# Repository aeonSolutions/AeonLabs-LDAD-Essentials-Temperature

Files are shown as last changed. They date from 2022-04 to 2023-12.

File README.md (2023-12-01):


  
 
 

<a href="https://trackgit.com">
trackgit-views
</a>




[](https://www.buymeacoffee.com/migueltomas)

<p align="center">
   
</p>

[Main Catalogue](https://github.com/aeonSolutions/PCB-Prototyping-Catalogue) >> 
[Construction Industry](https://github.com/aeonSolutions/PCB-Prototyping-Catalogue/tree/main/Construction%20Industry)  >>  Smart Technologies for Building Smart Network Connectivity

<p align="right">
 <a href="https://github-com.translate.goog/aeonSolutions/PCB-Prototyping-Catalogue/tree/main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">Change Language</a> <br>
Last update: 01-12-2023
</p>

# AeonLabs LDAD Essentials Temperature
This repo contains the KiCad files for the LDAD Essentials features up to 6 Temperature Sensors has WIFI and BLE connectivity and is powered by a 4.2v Lipo Battery.
This PCB was made to Fit a [Legrand Aftakdoos Leeq](https://www.google.com/search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) 89x43mm waterproof enclosure.

*Don't forget to LIKE , SHARE and subscribe the free whatsApp group* and if you liked this PCB consider buying me a cup of coffee. Links below.




### Status
  revision 1.0 tested and working

If you already tested this PCB send me a message. Thank you

## Revisions
- revision 1.0
  
## Download options
Download this repository if you need the KiCad Files or, download the Gerber files in the release section of this repository

## Liked it ? Get a Free PCB for yourself
Send me your Device or hardware and i will design a custom PCB for it. Free of charge. Contact-me on WhatsApp or email for more info. 

## Q&A WhatsApp Group
If you have any Questions or simply  like this kind of projects and want to stay updated with the latest research ideas and prototypes during the day and week, join the WhatsApp Group
[A.I. Things](https://chat.whatsapp.com/FkNC7u83kuy2QRA5sqjBVg)

## Fully assembled PCB
Alternatively, and if you do not want to build a PCB by yourself and like to buy one:

(https://www.tindie.com/stores/aeonlabs/)

The price starts at 30eur plus postage fees.
(I will also deliver the assembled PCB with all the components in place at a fair aditonal cost).

#### Be supportive of my dedication and work towards technology education and buy me a coffee. Link below.

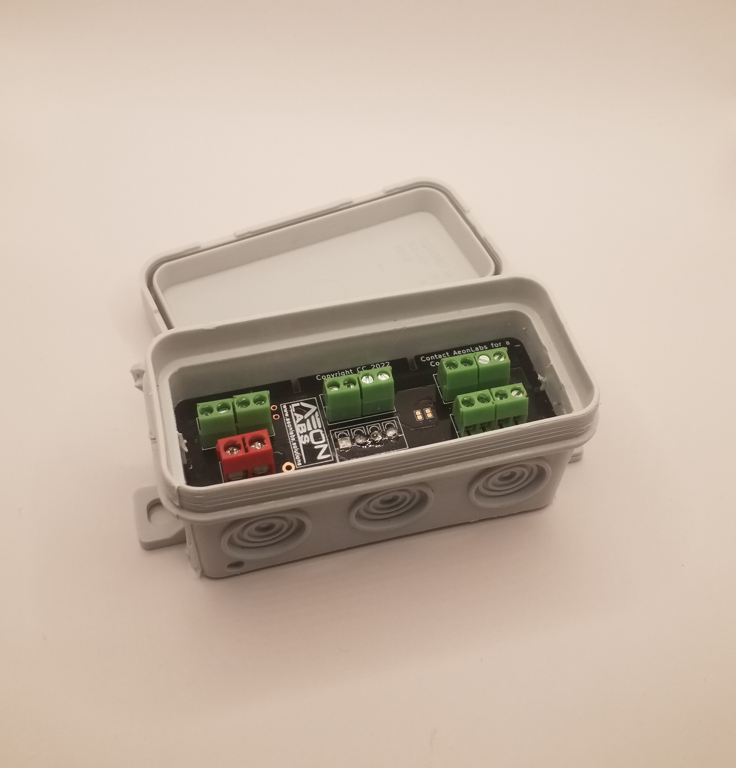
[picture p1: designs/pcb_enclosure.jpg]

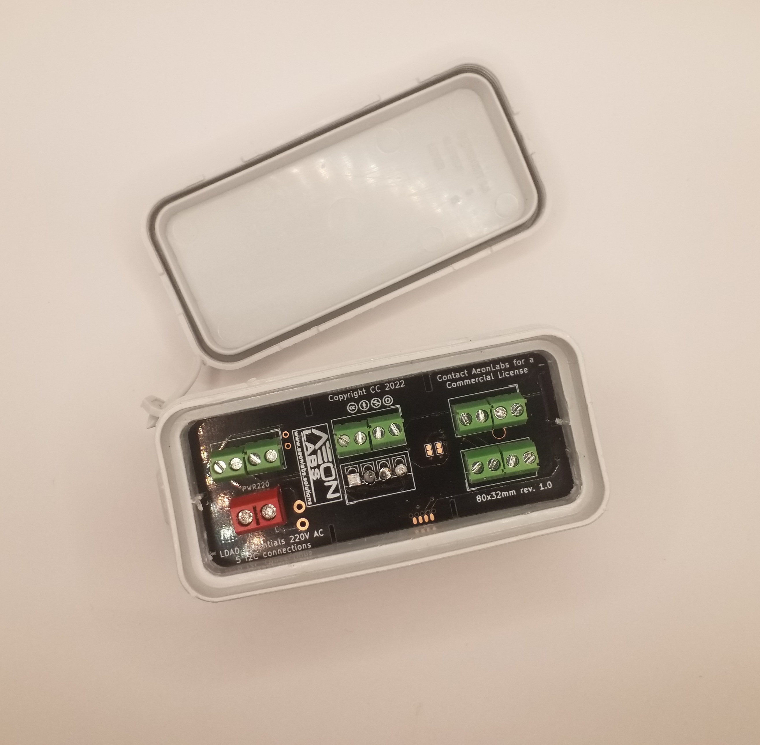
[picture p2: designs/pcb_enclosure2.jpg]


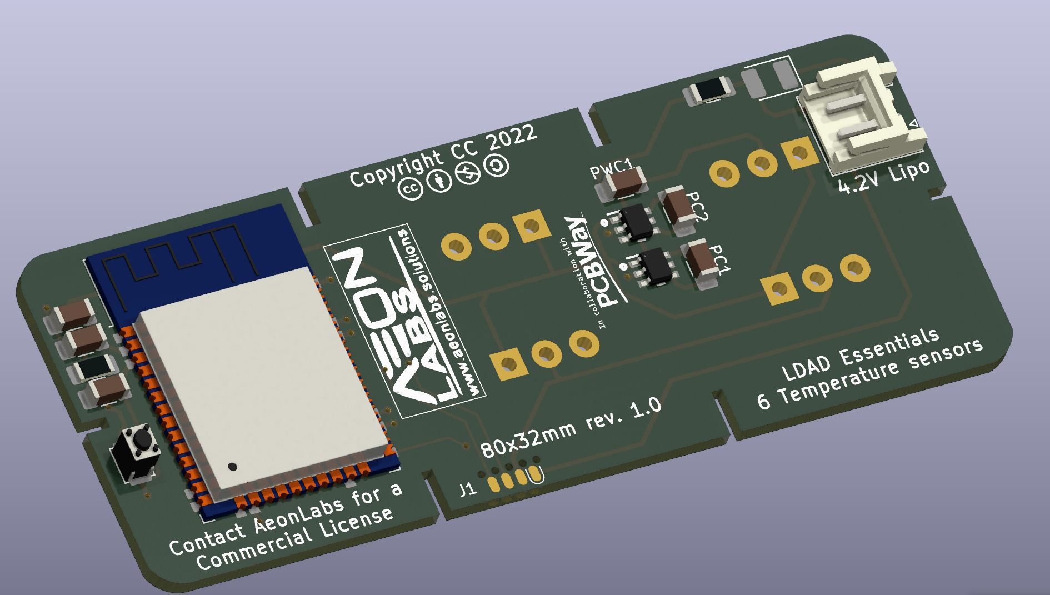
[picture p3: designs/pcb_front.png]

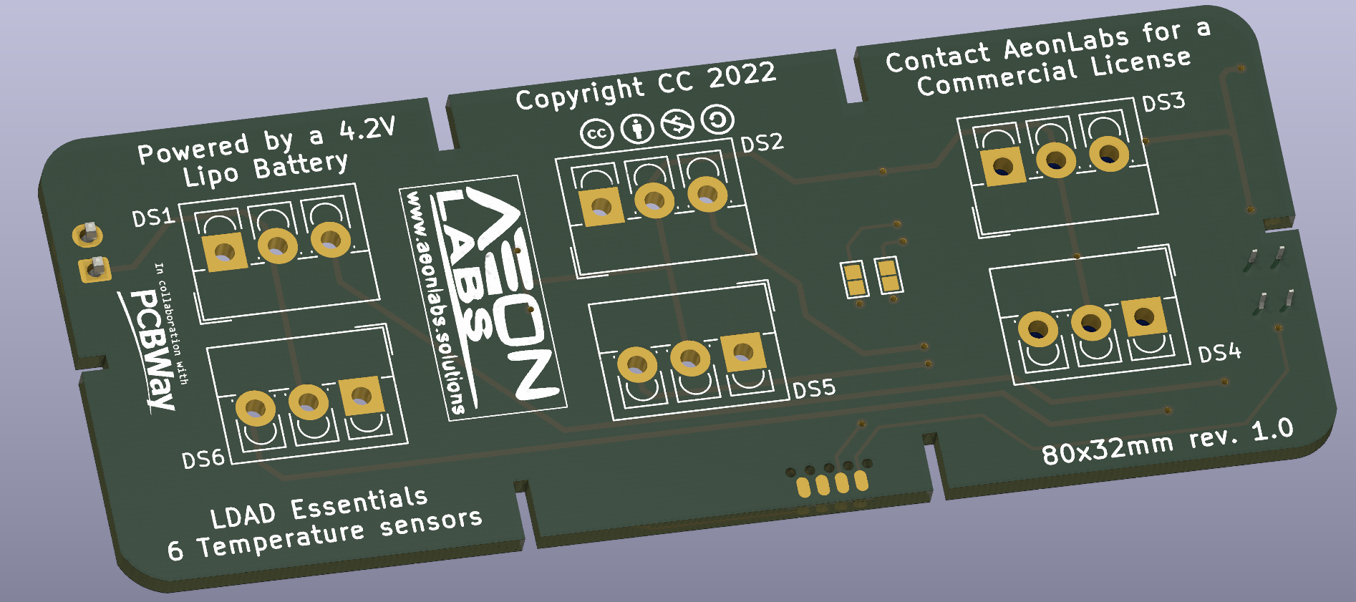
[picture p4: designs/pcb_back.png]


## PCB Parts list
- DC2DC converter HX4002B x2 : https://s.click.aliexpress.com/e/_Ak7IPx
- Capacitor 100nF SMD 1206 : https://s.click.aliexpress.com/e/_AVdmzr
- Capacitor 2.2uF SMD 1206 : https://s.click.aliexpress.com/e/_AVdmzr
- Resistor SMD 1206 330R x3 : https://s.click.aliexpress.com/e/_A7OXrR
- ESP32 WROOM32 x1 : https://s.click.aliexpress.com/e/_AF7N6l
- KF350 Screw pitch 3.5mm Straight 3 Pin pcb terminal block : https://s.click.aliexpress.com/e/_AChDnp

- This PCB connects with the DS18b20 Temperature sensor : https://s.click.aliexpress.com/e/_AWDAMr 

## PCB Enclosure
The enclosure for this PCB can be bought online by searching for "[Legrand Aftakdoos Leeq](https://www.google.com/search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)".

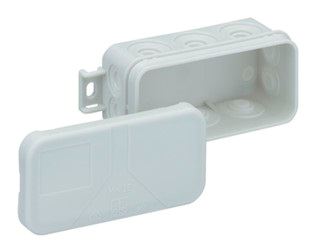
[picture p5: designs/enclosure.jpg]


## Firmware Download 
one can use the PCB in the repository [AeonLabs-MCU-Burner-USB-to-UART-TTL](https://github.com/aeonSolutions/AeonLabs-MCU-Burner-USB-to-UART-TTL) to program the ESP32 WROOM32 MCU on this PCB.

## Author

You can get in touch with me on my LinkedIn Profile:

#### Miguel Tomas



You can also follow my GitHub Profile to stay updated about my latest projects: 

<br>

### Be supportive of my dedication and work towards technology education and buy me a cup of coffee
The PCB Desgin Files i provide here for anyone to use are free. If you like this Smart Device or use it, please consider buying me a cup of coffee, a slice of pizza or a book to help me study, eat and think new PCB design files.

[](https://www.buymeacoffee.com/migueltomas)

<br />

### Make a donation on Paypal
Make a donation on paypal and get a TAX refund*.

(http://paypal.me/mtpsilva)

<br>

### Support all these open hardware projects and become a patreon  
Liked any of my PCB KiCad Designs? Help and Support my open work to all by becomming a LDAD Patreon.
In return I will give a free PCB design in KiCad to all patreon supporters. To learn more go to patreon.com. Link below.

(https://www.patreon.com/ldad)

#

### License

Before proceeding to download any of AeonLabs software solutions for open-source development and/or PCB hardware electronics solutions for open-hardware development make sure you are choosing the right license for your project. See [AeonLabs Solutions for Open Hardware & Source Development](https://github.com/aeonSolutions/PCB-Prototyping-Catalogue/wiki/AeonLabs-Solutions-for-Open-Hardware-&-Source-Development) for more information.

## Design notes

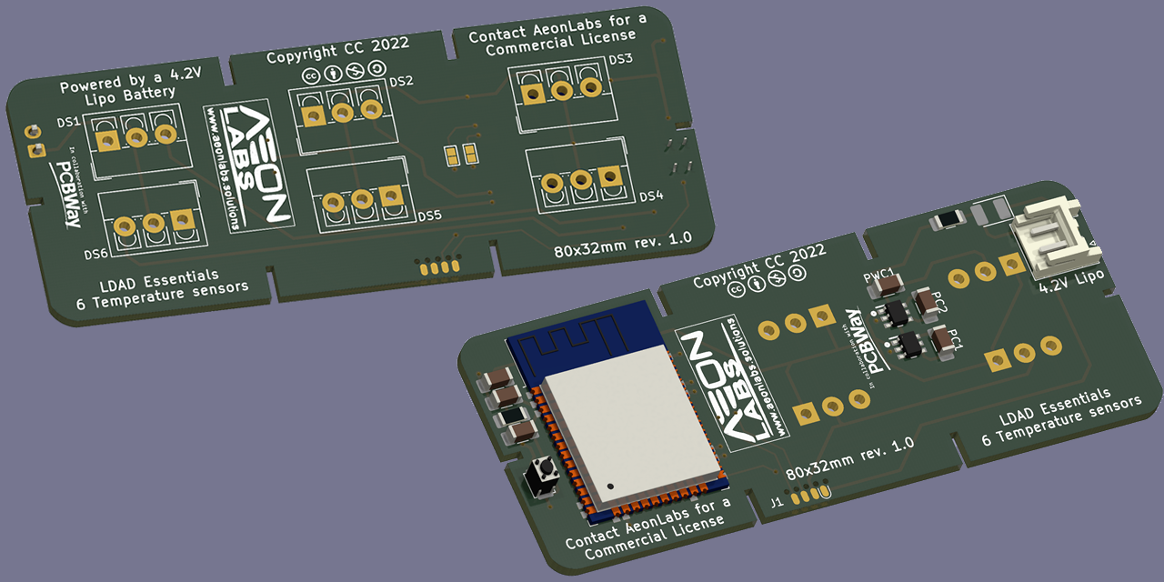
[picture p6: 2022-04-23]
designs/pcb.fw.png

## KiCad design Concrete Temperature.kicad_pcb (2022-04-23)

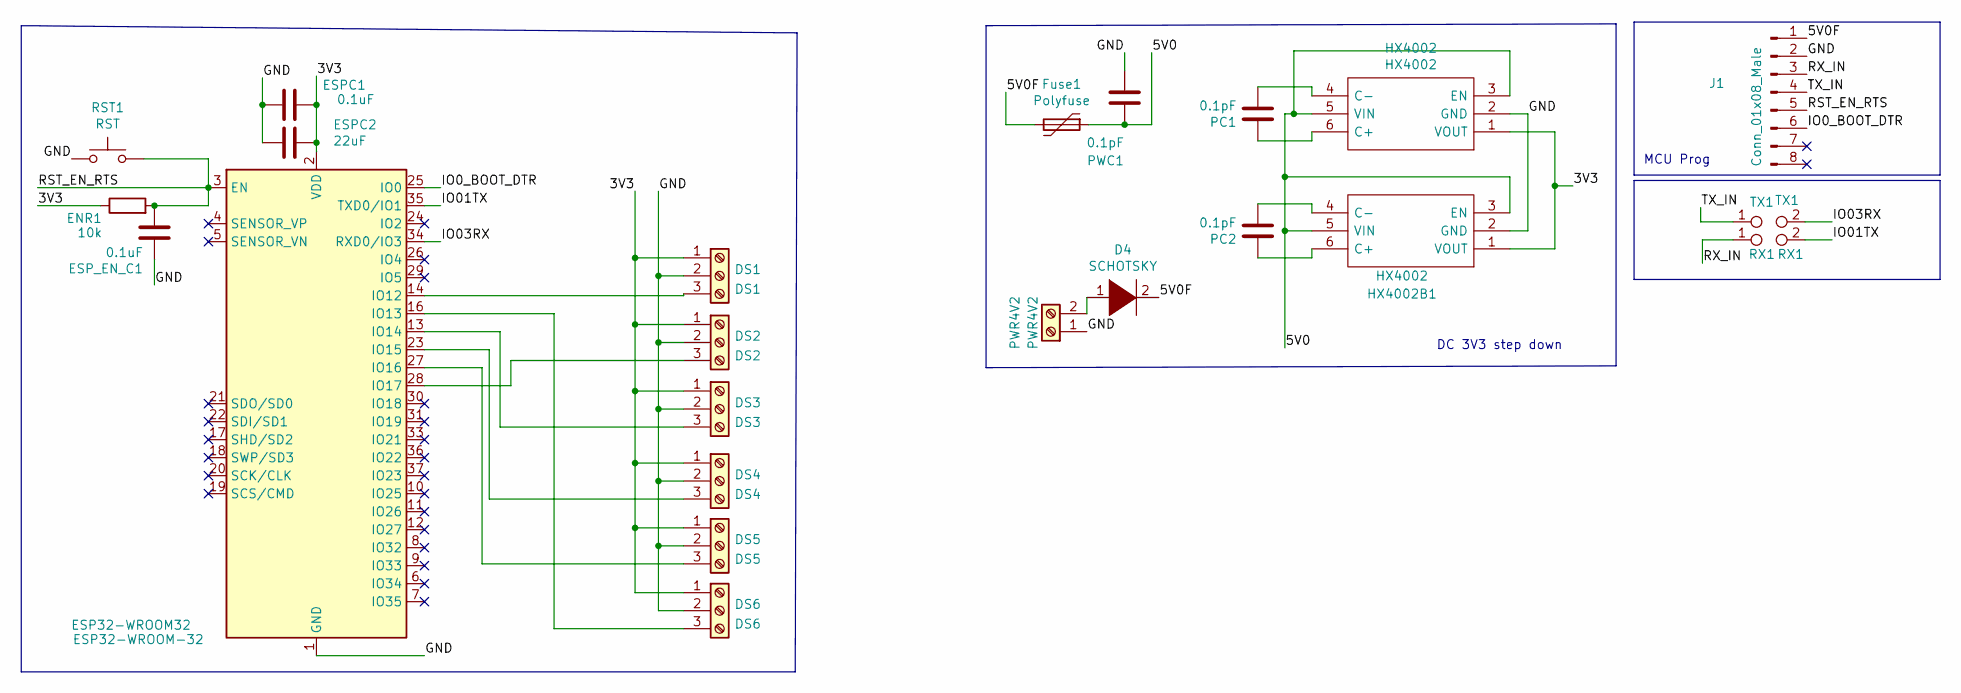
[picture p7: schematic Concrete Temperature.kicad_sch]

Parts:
D4: SCHOTSKY; D_1210_3225Metric_Pad1.42x2.65mm_HandSolder
DS1: DS1; TerminalBlock_4Ucon_1x03_P3.50mm_Vertical
DS2: DS2; TerminalBlock_4Ucon_1x03_P3.50mm_Vertical
DS3: DS3; TerminalBlock_4Ucon_1x03_P3.50mm_Vertical
DS4: DS4; TerminalBlock_4Ucon_1x03_P3.50mm_Vertical
DS5: DS5; TerminalBlock_4Ucon_1x03_P3.50mm_Vertical
DS6: DS6; TerminalBlock_4Ucon_1x03_P3.50mm_Vertical
ENR1: 10k; R_1206_3216Metric_Pad1.30x1.75mm_HandSolder
ESP32-WROOM32: ESP32-WROOM-32
ESPC1: 0.1uF; C_1206_3216Metric_Pad1.33x1.80mm_HandSolder
ESPC2: 22uF; C_1206_3216Metric_Pad1.33x1.80mm_HandSolder
ESP_EN_C1: 0.1uF; C_1206_3216Metric_Pad1.33x1.80mm_HandSolder
Fuse1: Polyfuse; Fuse_1206_3216Metric_Pad1.42x1.75mm_HandSolder
HX4002, HX4002B1: HX4002; HX4002 SOT95 P280X125-6N; Manufacturer_Part_Number HX4002
J1: Conn_01x08_Male; SOIC_clipProgSmall
PC1, PC2: 0.1pF; C_1206_3216Metric_Pad1.33x1.80mm_HandSolder
PWC1: 0.1pF; C_1206_3216Metric_Pad1.33x1.80mm_HandSolder
PWR4V2: PWR4V2; JST_EH_S2B-EH_1x02_P2.50mm_Horizontal
RST1: RST; SW_Push_SPST_NO_Alps_SKRK AliExpress
RX1: RX1; TestPoint_Pad_Bridge_1.0x1.0mm
TX1: TX1; TestPoint_Pad_Bridge_1.0x1.0mm

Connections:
/3V3: DS1.1, DS2.1, DS3.1, DS4.1, DS5.1, DS6.1, ENR1.1, ESP32-WROOM32.2 (VDD), ESPC1.1, ESPC2.1, HX4002.1 (VOUT), HX4002B1.1 (VOUT)
/5V0: Fuse1.1, HX4002.3 (EN), HX4002.5 (VIN), HX4002B1.3 (EN), HX4002B1.5 (VIN), PWC1.1
/5V0F: D4.2 (A), Fuse1.2, J1.1
/GND: DS1.2, DS2.2, DS3.2, DS4.2, DS5.2, DS6.2, ESP32-WROOM32.1 (GND), ESP32-WROOM32.15 (GND), ESP32-WROOM32.38 (GND), ESP32-WROOM32.39 (GND), ESPC1.2, ESPC2.2, ESP_EN_C1.1, HX4002.2 (GND), HX4002B1.2 (GND), J1.2, PWC1.2, PWR4V2.1, RST1.1
/IO0_BOOT_DTR: ESP32-WROOM32.25 (IO0), J1.6
/IO01TX: ESP32-WROOM32.35 (TXD0/IO1), RX1.2
/IO03RX: ESP32-WROOM32.34 (RXD0/IO3), TX1.2
/RST_EN_RTS: ENR1.2, ESP32-WROOM32.3 (EN), ESP_EN_C1.2, J1.5, RST1.2
/RX_IN: J1.3, RX1.1
/TX_IN: J1.4, TX1.1
unnamed: DS1.3, ESP32-WROOM32.14 (IO12)
unnamed: DS2.3, ESP32-WROOM32.28 (IO17)
unnamed: DS3.3, ESP32-WROOM32.13 (IO14)
unnamed: DS4.3, ESP32-WROOM32.23 (IO15)
unnamed: DS5.3, ESP32-WROOM32.27 (IO16)
unnamed: DS6.3, ESP32-WROOM32.16 (IO13)
unnamed: HX4002.4 (C-), PC1.2
unnamed: HX4002.6 (C+), PC1.1
unnamed: HX4002B1.4 (C-), PC2.2
unnamed: HX4002B1.6 (C+), PC2.1
unnamed: D4.1 (K), PWR4V2.2

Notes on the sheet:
DC 3V3 step down
MCU Prog

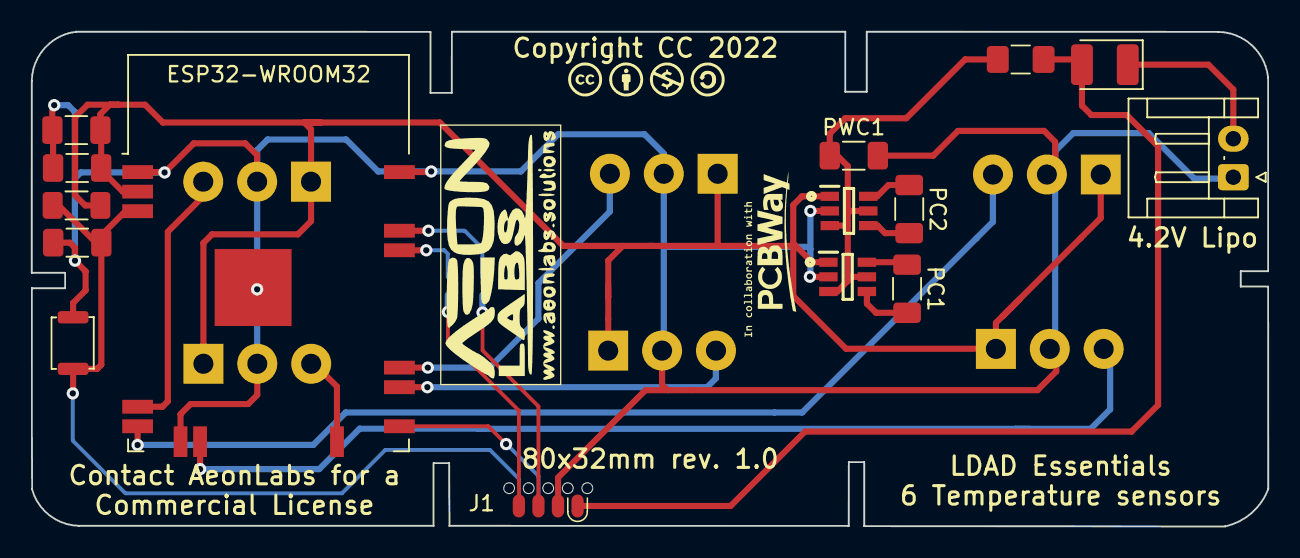
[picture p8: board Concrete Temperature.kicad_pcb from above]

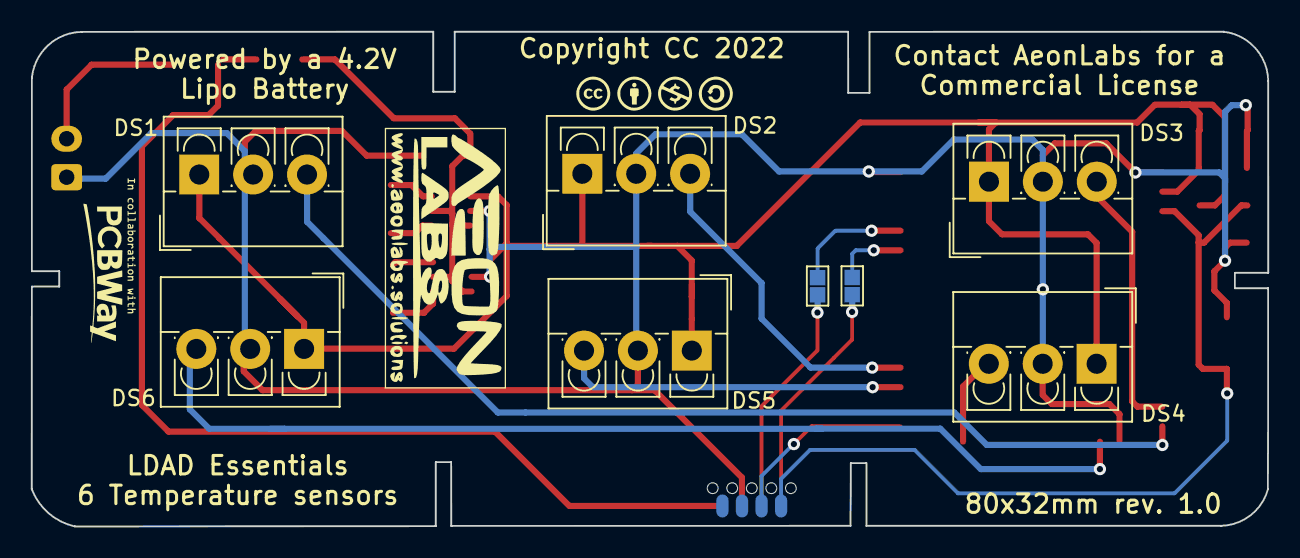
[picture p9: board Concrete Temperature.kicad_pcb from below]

Board: 2 copper layers, 80.3 x 32.1 mm, 23 parts (8 on the bottom side), 21 nets.

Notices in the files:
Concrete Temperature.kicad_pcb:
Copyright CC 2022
